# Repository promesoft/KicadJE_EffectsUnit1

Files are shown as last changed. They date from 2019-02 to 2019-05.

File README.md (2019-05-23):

# KicadJE_EffectsUnit1
JE-EU1 - PT2399 based reverb - distortion units
Eurorack form factor

# MK1 Design
## Status - operational
# Status - Secondary tests
## Initial 
| Stage  | Detail | Status |
| --- | --- | --- |
| create material  | sch/pcb | produced Rev A  |
| | gerber | Produced |
| production  | ordered  | YES |
|  | produced | YES |
|  | delivered | YES |
## Preliminary validation
| Test  | Detail | Status |
| --- | --- | --- |
| Initial Inspection |  | OK |
| Initial Technical Test | PT2399 | OK - See Errata |
| Initial Technical Test | Counter  | OK |
| Initial Technical Test | Bitcrunch |  |
| Initial Product Test | PT2399 | OK |
| Initial Product Test | Counter | OK |
| Initial Product Test | Bitcrunch  | OK - LFO w Distortion |
| Initial Power Consumption | PT2399 | 40-60mA ! +12v depending on VCO circuit |
| Initial Power Consumption | Counter | 20mA +12v  |
| Initial Power Consumption | Bitcrunch | +12v +5v -12v |
| Initial Power Consumption | LFO | +12v +5v -12v |

## Secondary validation
| Test  | Detail | Status |
| --- | --- |--- |
| Product Test | PT2399 | ok after mod |
| Product Test | Counter | OK |
| Product Test | LFO Distortion | OK - dist too much |
| Product Test | Bitcrush Distortion |  |
| Quality | LFO | good - distortion is questionable effect |
| Quality | Bitcrush |  |
| Quality | Counter | Good - needs input prot |
| Quality | PT2399 | ongoing |
| Long Term Product Test | PT2399 | Modded version installed in rack |
| Long Term Product Test | Counter | installed in rack |
| Long Term Product Test | Bitcrush |  |
| Long Term Product Test | LFO | installed in rack |

## Software 
| Test  | Detail | Status |
| --- | --- |--- |
| Initial SW | copy from MK1 and adjusted | OK! |
| Bitcrush | UI | |
| Bitcrush | Crush function | |
| LFO Control | UI | Individual speed and waveform impl |
| LFO Control | Function | Individual LFO implemented |
| LFO Control | Input | 3x Trigger done |

## Errata
### ERRATA - PT2399
 * 78L05 inv pinout
 * MMBT2222 wrong pinout - workaround flip and turn
 * Delay time pot reversed
 * PT2399 occational latchup with modification
 * SW101 and S105W are wired wrong to enable Dist on/off
### ERRATA - Counter
### ERRATA - Bitcrunch
 * SW 101 and SW105 should change footprint (too small for MT202)
 * D110 and D111 is 0805 and cannot be fitted with SOD123
## Issues and Notes
### Issues and Notes - PT2399
 * Replace 20k across Q203 w Yellow LED
 * Replace 120k R214 with 47k
 * Move C222 across RV202 - move D2015 across R214 and remove Q202+R213
 * Consider Vactrol of RV202 and RV201
 * Consider +5V supply...
### Issues and Notes - Counter
 * Replace 100uF C310 with 10-22uF (consider a switch for next rev)
 * Reset/Clk in Trigger not 5V tolerant
 * Add I/O protection

### Issues and Notes - Bit Crunch
LFO only values:
 * 11k = 10k
 * 22k = 10k
 * 33k = 10k
 * 44k = 10k
 * 11n = 100n
 * 22n = 100n
 * 33n = 100n
 * 44n = 100n
 * D118 - D117 remove
 * Optional D111 - D110
Dist/Bitcrush values has been added to the sch
 * Move LED D114 closer to Out9

### Workarounds

## Base Construction 
The idea is to have 3 different units.
Practically it may be required to fit the bitcrusher and the distortion in one unit.
### Distortion base board with Arduino Bitcrusher
 - 16pin Europower connector
 
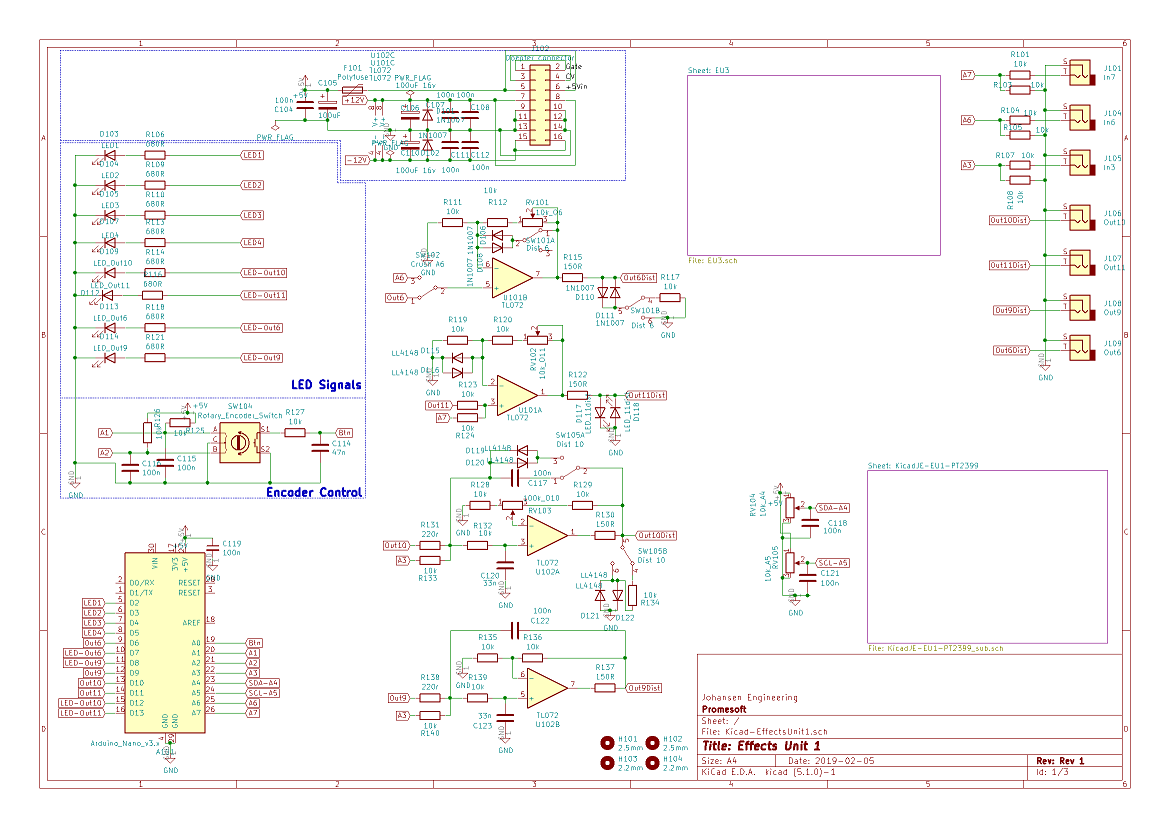
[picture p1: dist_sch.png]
 

### PT2399 base board 
 - 10pin Europower connector
 - BC547 or BC337 NPN and Zener 7v5 regulator followed by 78L05 regulator
 - PT2399 echo circuit with anti lockup circuit for pin 6
 - 
### Binary counter and clock
 - 10pin Europower connector
 - Build around a CD4017 counter chip (SOP-14)
 
 
 


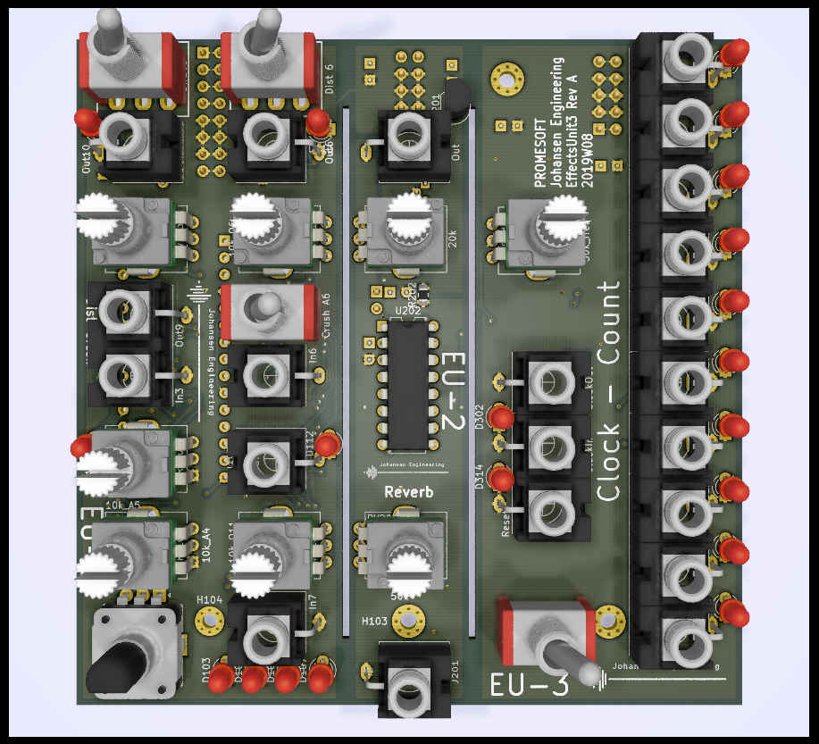
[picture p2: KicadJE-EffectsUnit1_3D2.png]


## Vital Components
 - Arduino Nano
 - PT2399
 - CD4017
 - NE555
 - Mini Jacks (PJ-321) 
 - ALPS RV09 potentiometer
 - TL072 or similar dual op amp
 - Diode clipping (silicium signal diodes, LED, power, shottkey, germanium
 
### Mechanical


The construction is inspired from
-----------------------------------------------------
 - https://www.electronics-tutorials.ws/waveforms/555_oscillator.html (Counter clock)
 - https://www.electrosmash.com/pt2399-analysis (PT2399 Reverb)
 - http://sim.okawa-denshi.jp/en/OPttool.php (Filter calc for MFB filter)
 - http://sim.okawa-denshi.jp/en/OPseikiLowkeisan.htm (Filter calc for Sallen Key filter (Out9 and Out10))

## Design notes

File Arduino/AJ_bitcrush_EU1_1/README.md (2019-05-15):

Left lower input is sampled as fast as possible

Output to all digital outputs with an AND function on the lower 16 bits with the "state" information equivalent to the LED readout

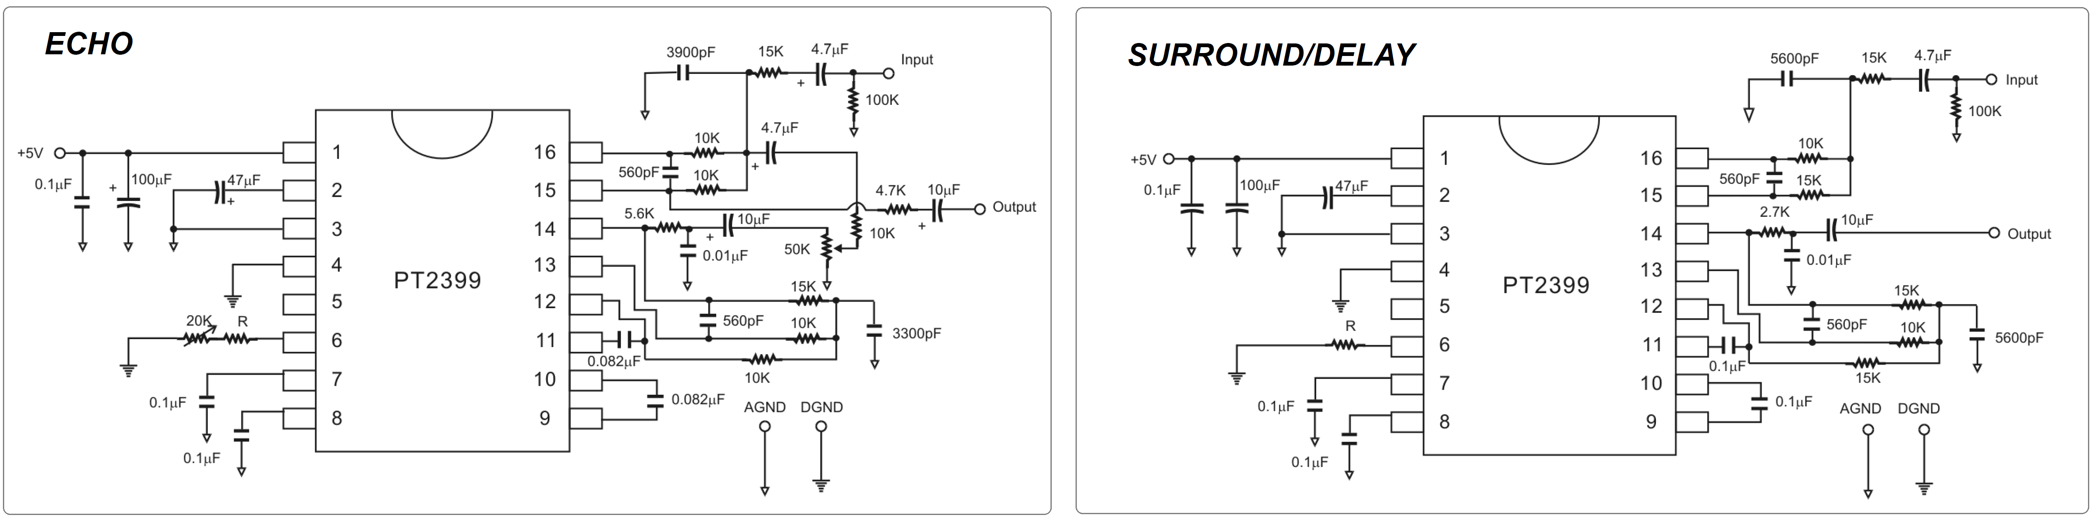
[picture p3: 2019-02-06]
PT2399_echo_delay.png

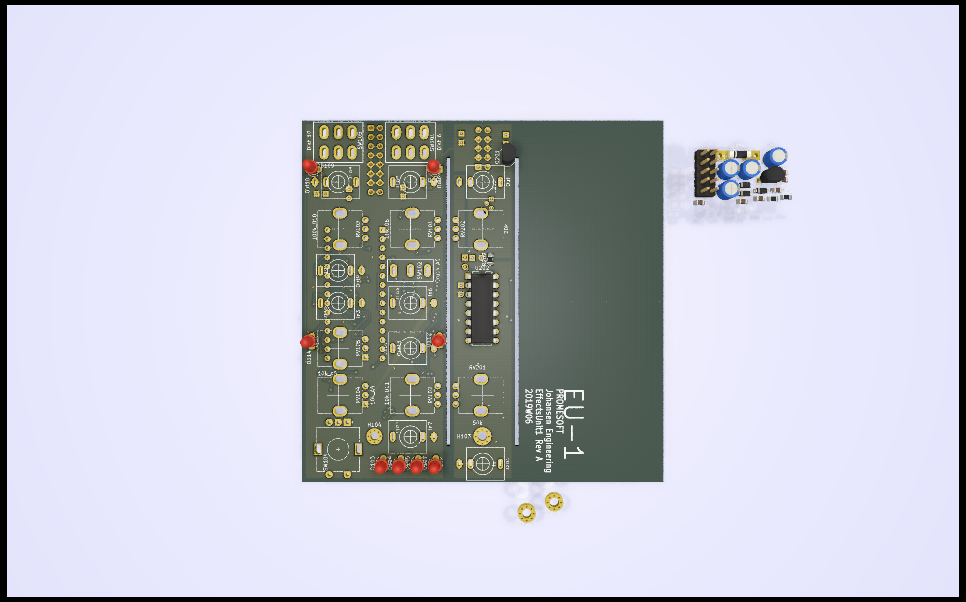
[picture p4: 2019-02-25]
KicadJE-EffectsUnit1_3D1.png

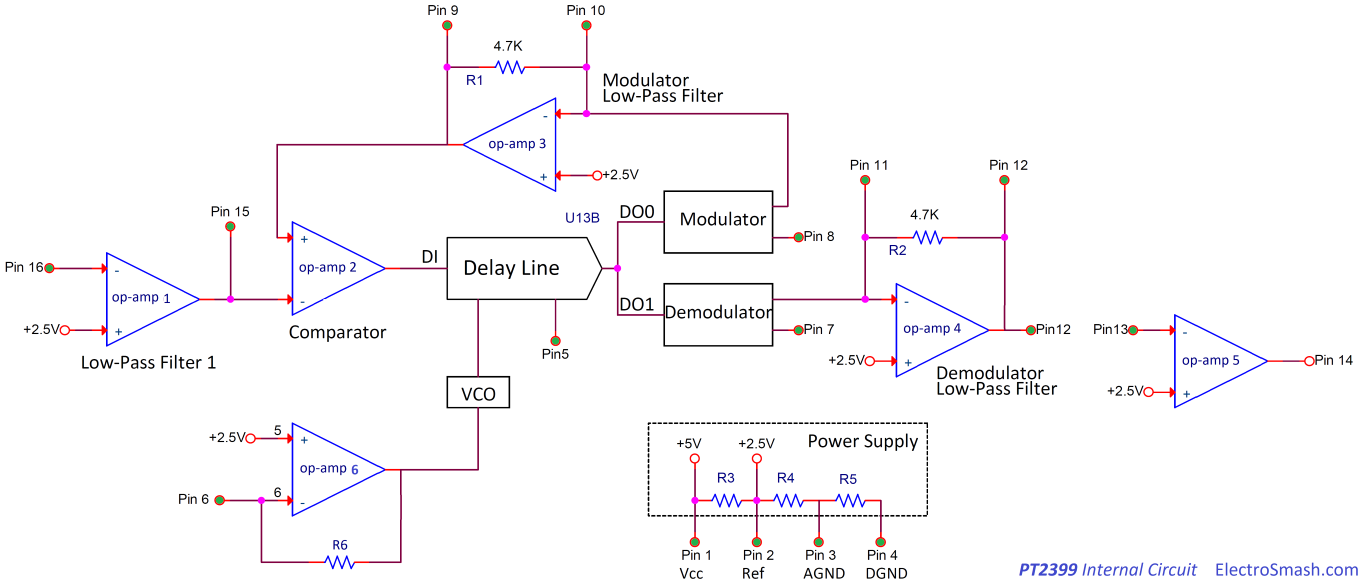
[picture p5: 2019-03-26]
PT2399_Internal_Circuit_small.png

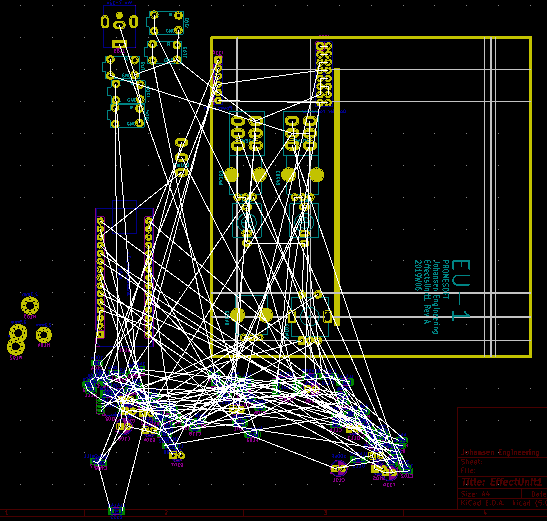
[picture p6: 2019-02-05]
KicadJE-EffectsUnit1.lib.png

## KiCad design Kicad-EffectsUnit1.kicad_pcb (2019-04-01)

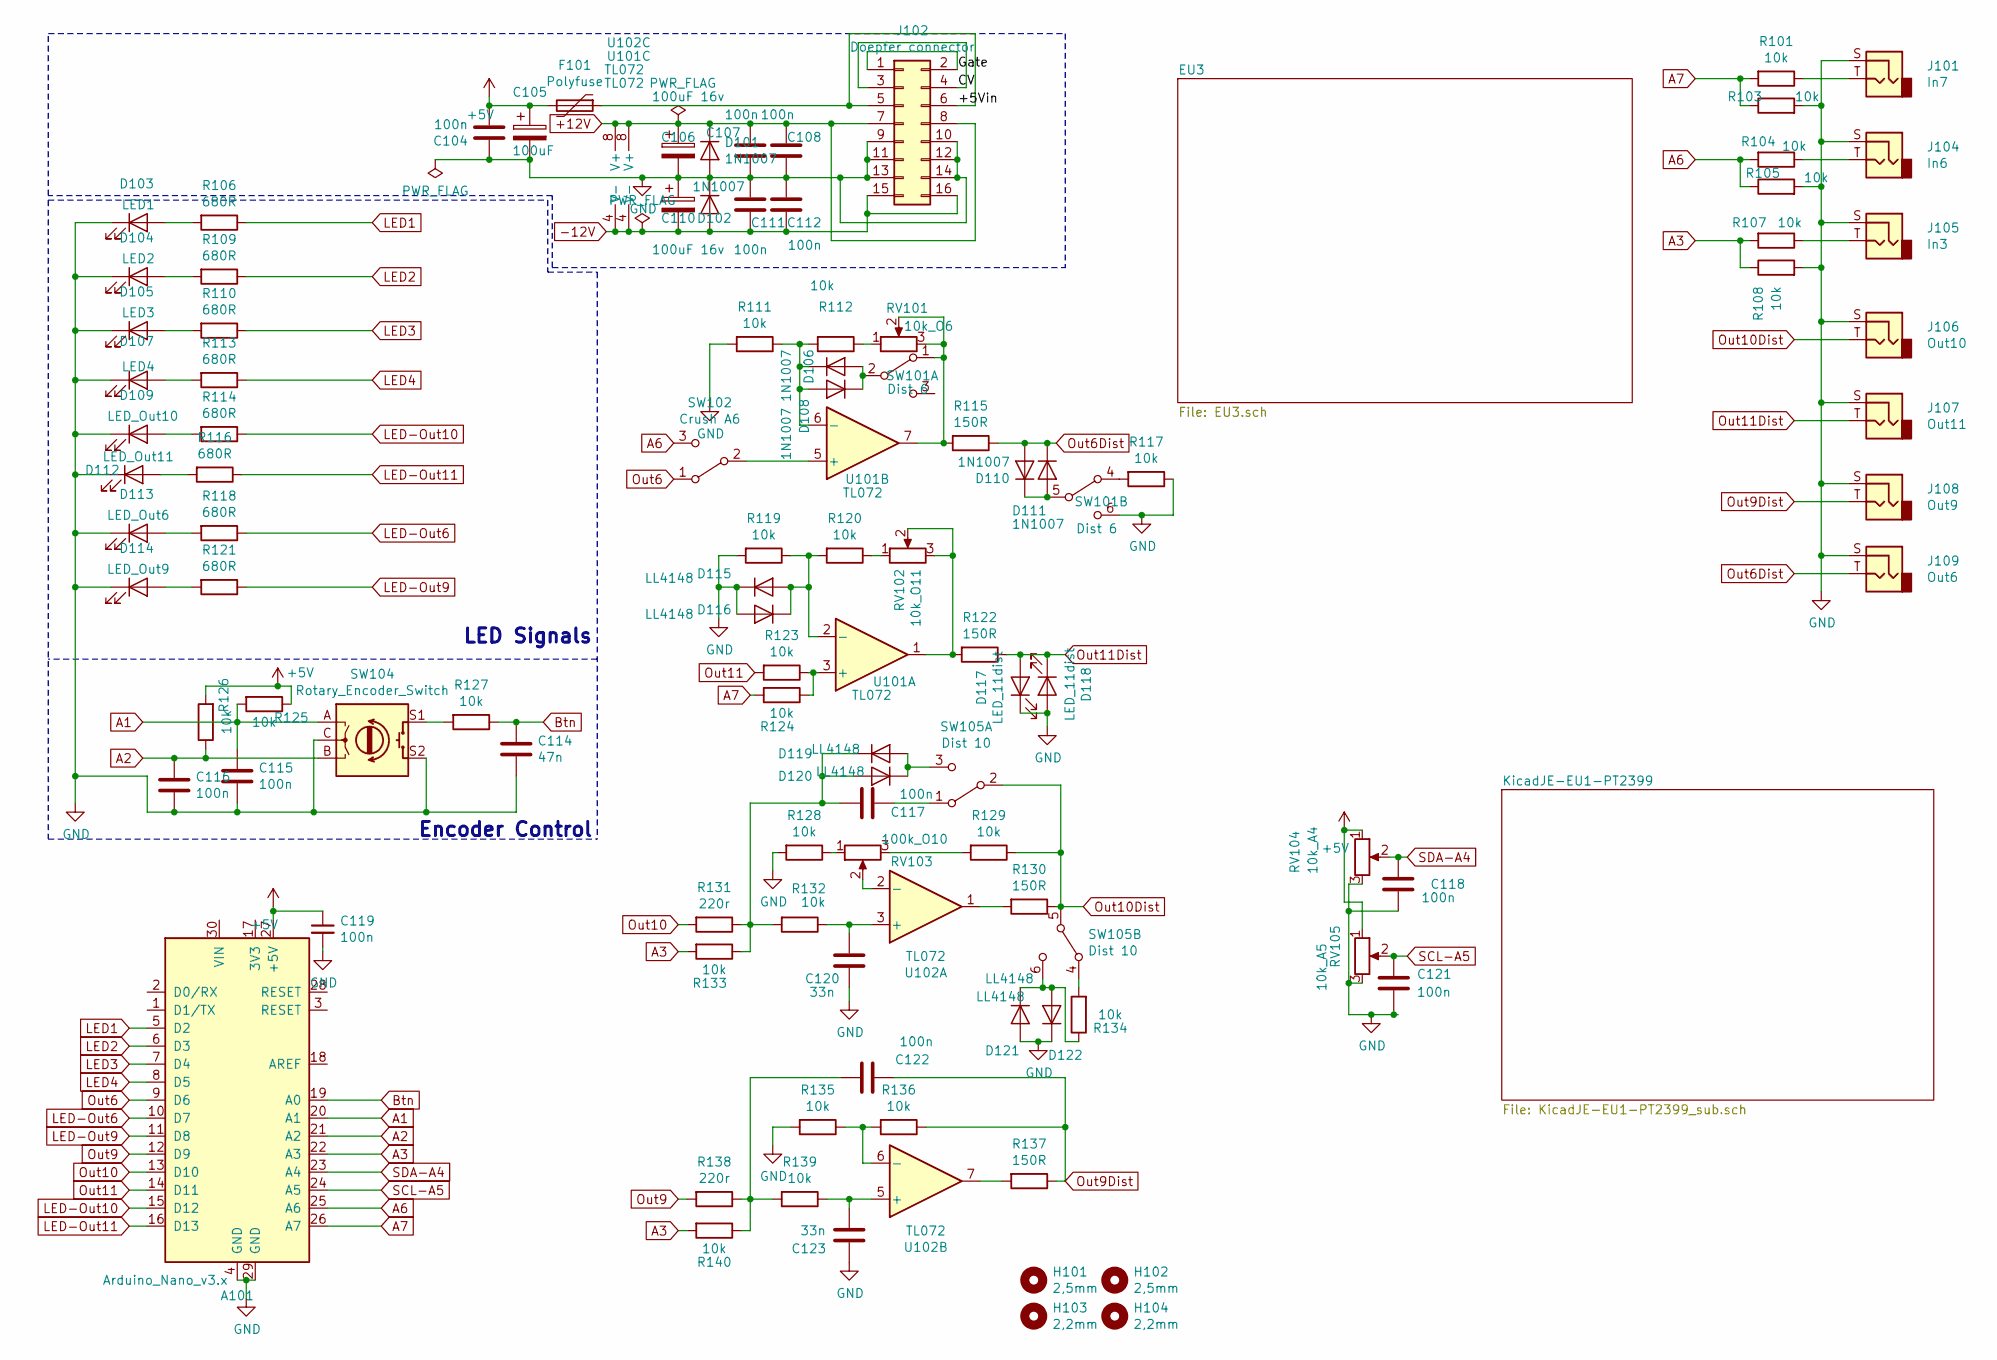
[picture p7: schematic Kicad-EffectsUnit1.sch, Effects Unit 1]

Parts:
A101: Arduino_Nano_v3.x; Arduino_Nano
C104, C107, C108, C111, C112, C115, C116, C117, C118, C119, C121, C122: 100n; C_0805_2012Metric_Pad1.15x1.40mm_HandSolder
C105: 100uF; CP_Radial_D5.0mm_P2.50mm
C106, C110: 100uF 16v; CP_Radial_D5.0mm_P2.50mm
C114: 47n; C_0805_2012Metric_Pad1.15x1.40mm_HandSolder
C120, C123: 33n; C_0805_2012Metric_Pad1.15x1.40mm_HandSolder
D101, D102, D106, D108: 1N1007; D_SOD-123
D103: LED1; LED_D3.0mm
D104: LED2; LED_D3.0mm
D105: LED3; LED_D3.0mm
D107: LED4; LED_D3.0mm
D109: LED_Out10; LED_D3.0mm
D110, D111: 1N1007; D_0805_2012Metric_Pad1.15x1.40mm_HandSolder
D112: LED_Out11; LED_D3.0mm
D113: LED_Out6; LED_D3.0mm
D114: LED_Out9; LED_D3.0mm
D115, D116, D119, D120, D121, D122: LL4148; D_MiniMELF
D117: LED_11dist; LED_0805_2012Metric_Pad1.15x1.40mm_HandSolder
D118: LED_11dist; D_0805_2012Metric_Pad1.15x1.40mm_HandSolder
F101: Polyfuse; Fuse_1206_3216Metric_Pad1.42x1.75mm_HandSolder
H101, H102: 2,5mm; MountingHole_2.5mm_Pad_Via
H103: 2,2mm; MountingHole_2.5mm_Pad_Via
H104: 2,2mm; MountingHole_2.2mm_M2_Pad_Via
J101: In7; PJ301SM
J102: Doepfer connector; PinSocket_2x08_P2.54mm_Vertical
J104: In6; PJ301SM
J105: In3; PJ301SM
J106: Out10; PJ301SM
J107: Out11; PJ301SM
J108: Out9; PJ301SM
J109: Out6; PJ301SM
R101, R103, R104, R105, R107, R108, R111, R112, R117, R119, R120, R123, R124, R125, R126, R127, R128, R129, R132, R133, R134, R135, R136, R139, R140: 10k; R_0805_2012Metric_Pad1.15x1.40mm_HandSolder
R106, R109, R110, R113, R114, R116, R118, R121: 680R; R_0805_2012Metric_Pad1.15x1.40mm_HandSolder
R115, R122, R130, R137: 150R; R_0805_2012Metric_Pad1.15x1.40mm_HandSolder
R131, R138: 220r; R_0805_2012Metric_Pad1.15x1.40mm_HandSolder
RV101: 10k_O6; Potentiometer_China_RK09_Single_Vertical_AJ
RV102: 10k_O11; Potentiometer_China_RK09_Single_Vertical_AJ
RV103: 100k_O10; Potentiometer_China_RK09_Single_Vertical_AJ
RV104: 10k_A4; Potentiometer_China_RK09_Single_Vertical_AJ
RV105: 10k_A5; Potentiometer_China_RK09_Single_Vertical_AJ
SW101: Dist 6; SPDTx2
SW102: Crush A6; SP1MS1
SW104: Rotary_Encoder_Switch; RotaryEncoder_Alps_EC11E-Switch_Vertical_H20mm
SW105: Dist 10; SPDTx2
U101, U102: TL072; AJ_SO-8_5.3x6.2mm_P1.27mm

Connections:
+5V: A101.27 (+5V), C104.2, C105.1, C119.1, F101.2, R125.1, R126.2, RV104.1, RV105.1
+12V: C106.1, C107.2, C108.2, D101.1 (K), J102.7, J102.8, U101.8 (V+), U102.8 (V+)
-12V: C110.2, C111.1, C112.1, D102.2 (A), J102.15, J102.16, U101.4 (V-), U102.4 (V-)
/+5Vin: F101.1, J102.5, J102.6
/CV: J102.3, J102.4
/Gate: J102.1, J102.2
A1: A101.20 (A1), C115.1, R125.2, SW104.A
A2: A101.21 (A2), C116.1, R126.1, SW104.B
A3: A101.22 (A3), R107.2, R108.1, R133.2, R140.2
A6: A101.25 (A6), R104.2, R105.1, SW102.3 (C)
A7: A101.26 (A7), R101.2, R103.1, R124.2
Btn: A101.19 (A0), C114.1, R127.1
GND: A101.4 (GND), A101.29 (GND), C104.1, C105.2, C106.2, C107.1, C108.1, C110.1, C111.2, C112.2, C114.2, C115.2, C116.2, C118.2, C119.2, C120.2, C121.2, C123.2, D101.2 (A), D102.1 (K), D103.1 (K), D104.1 (K), D105.1 (K), D107.1 (K), D109.1 (K), D112.1 (K), D113.1 (K), D114.1 (K), D115.1 (K), D116.2 (A), D117.1 (K), D118.2 (A), D121.2 (A), D122.1 (K), J101.S, J102.9, J102.10, J102.11, J102.12, J102.13, J102.14, J104.S, J105.S, J106.S, J107.S, J108.S, J109.S, R103.2, R105.2, R108.2, R111.2, R117.1, R119.2, R128.2, R135.2, RV104.3, RV105.3, SW101.6 (C), SW104.C, SW104.S2; also elsewhere on the board
LED1: A101.5 (D2), R106.1
LED2: A101.6 (D3), R109.1
LED3: A101.7 (D4), R110.1
LED4: A101.8 (D5), R113.1
LED-Out6: A101.10 (D7), R118.1
LED-Out9: A101.11 (D8), R121.1
LED-Out10: A101.15 (D12), R114.1
LED-Out11: A101.16 (D13), R116.1
unnamed: C117.1, SW105.1 (A)
unnamed: C117.2, D119.1 (K), D120.2 (A), R131.1, R132.2, R133.1
unnamed: C120.1, R132.1, U102.3 (+)
unnamed: C122.2, R138.1, R139.2, R140.1
unnamed: C123.1, R139.1, U102.5 (+)
unnamed: D103.2 (A), R106.2
unnamed: D104.2 (A), R109.2
unnamed: D105.2 (A), R110.2
unnamed: D106.1 (K), D108.2 (A), R111.1, R112.2, U101.6 (-)
unnamed: D106.2 (A), D108.1 (K), SW101.2 (B)
unnamed: D107.2 (A), R113.2
unnamed: D109.2 (A), R114.2
unnamed: D110.1 (K), D111.2 (A), SW101.5 (B)
unnamed: D112.2 (A), R116.2
unnamed: D113.2 (A), R118.2
unnamed: D114.2 (A), R121.2
unnamed: D115.2 (A), D116.1 (K), R119.1, R120.2, U101.2 (-)
unnamed: D119.2 (A), D120.1 (K), SW105.3 (C)
unnamed: D121.1 (K), D122.2 (A), R134.1, SW105.6 (C)
unnamed: J101.T, R101.1
unnamed: J104.T, R104.1
unnamed: J105.T, R107.1
unnamed: R112.1, RV101.1
unnamed: R115.2, RV101.2, RV101.3, SW101.1 (A), U101.7
unnamed: R117.2, SW101.4 (A)
unnamed: R120.1, RV102.1
unnamed: R122.2, RV102.2, RV102.3, U101.1
unnamed: R123.1, R124.1, U101.3 (+)
unnamed: R127.2, SW104.S1
unnamed: R128.1, RV103.1
unnamed: R129.2, RV103.3
unnamed: R130.2, U102.1
unnamed: R134.2, SW105.4 (A)
unnamed: R135.1, R136.2, U102.6 (-)
unnamed: R137.2, U102.7
unnamed: RV103.2, U102.2 (-)
unnamed: SW102.2 (B), U101.5 (+)
Out6: A101.9 (D6), SW102.1 (A); also elsewhere on the board
Out6Dist: D110.2 (A), D111.1 (K), J109.T, R115.1
Out9: A101.12 (D9), R138.2; also elsewhere on the board
Out9Dist: C122.1, J108.T, R136.1, R137.1
Out10: A101.13 (D10), R131.2
Out10Dist: J106.T, R129.1, R130.1, SW105.2 (B), SW105.5 (B)
Out11: A101.14 (D11), R123.2
Out11Dist: D117.2 (A), D118.1 (K), J107.T, R122.1
SCL-A5: A101.24 (A5), C121.1, RV105.2
SDA-A4: A101.23 (A4), C118.1, RV104.2

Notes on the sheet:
LED Signals
Encoder Control

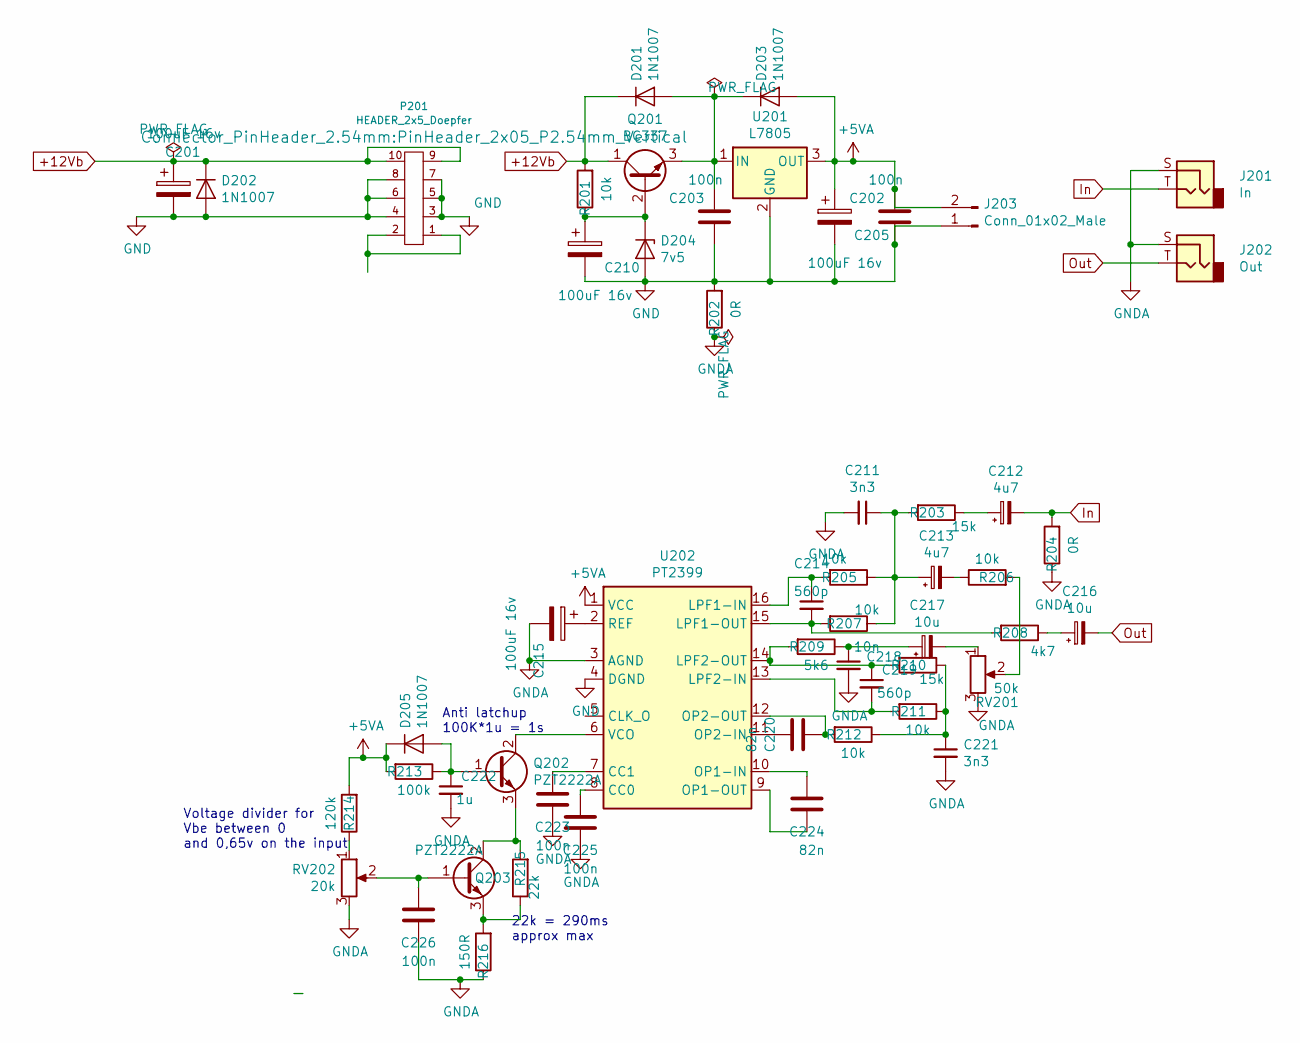
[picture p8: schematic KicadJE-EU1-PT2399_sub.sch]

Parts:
C201, C205, C210, C215: 100uF 16v; CP_Radial_D5.0mm_P2.50mm
C202, C203, C223, C225, C226: 100n; C_0805_2012Metric_Pad1.15x1.40mm_HandSolder
C211, C221: 3n3; C_0805_2012Metric_Pad1.15x1.40mm_HandSolder
C212, C213: 4u7; C_0805_2012Metric_Pad1.15x1.40mm_HandSolder
C214, C219: 560p; C_0805_2012Metric_Pad1.15x1.40mm_HandSolder
C216, C217: 10u; C_0805_2012Metric_Pad1.15x1.40mm_HandSolder
C218: 10n; C_0805_2012Metric_Pad1.15x1.40mm_HandSolder
C220, C224: 82n; C_0805_2012Metric_Pad1.15x1.40mm_HandSolder
C222: 1u; C_0805_2012Metric_Pad1.15x1.40mm_HandSolder
D201, D202, D203, D205: 1N1007; D_SOD-123
D204: 7v5; D_MiniMELF
J201: In; PJ301SM
J202: Out; PJ301SM
J203: Conn_01x02_Male; PinHeader_1x02_P2.54mm_Vertical
P201: HEADER_2x5_Doepfer; PinHeader_2x05_P2.54mm_Vertical
Q201: BC337; TO-92_Inline
Q202, Q203: PZT2222A; SOT-23
R201, R205, R206, R207, R211, R212: 10k; R_0805_2012Metric_Pad1.15x1.40mm_HandSolder
R202, R204: 0R; R_0805_2012Metric_Pad1.15x1.40mm_HandSolder
R203, R210: 15k; R_0805_2012Metric_Pad1.15x1.40mm_HandSolder
R208: 4k7; R_0805_2012Metric_Pad1.15x1.40mm_HandSolder
R209: 5k6; R_0805_2012Metric_Pad1.15x1.40mm_HandSolder
R213: 100k; R_0805_2012Metric_Pad1.15x1.40mm_HandSolder
R214: 120k; R_0805_2012Metric_Pad1.15x1.40mm_HandSolder
R215: 22k; R_0805_2012Metric_Pad1.15x1.40mm_HandSolder
R216: 150R; R_0805_2012Metric_Pad1.15x1.40mm_HandSolder
RV201: 50k; Potentiometer_China_RK09_Single_Vertical_AJ
RV202: 20k; Potentiometer_China_RK09_Single_Vertical_AJ
U201: L7805; TO-92
U202: PT2399; DIP-16_W7.62mm

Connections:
+5VA: C202.2, C205.1, D203.2 (A), D205.1 (K), J203.2, R213.2, R214.2, U201.3 (OUT), U202.1 (VCC)
+12Vb: C201.1, D201.1 (K), D202.1 (K), P201.9 (+12), P201.10 (+12), Q201.1 (C), R201.2
GND: C201.2, C202.1, C203.1, C205.2, C210.2, D202.2 (A), D204.2 (A), J203.1, P201.3 (GND), P201.4 (GND), P201.5 (GND), P201.6 (GND), P201.7 (GND), P201.8 (GND), R202.2, U201.2 (GND), U202.4 (DGND); also elsewhere on the board
GNDA: C211.2, C215.2, C218.2, C221.2, C222.2, C223.1, C225.1, C226.1, J201.S, J202.S, R202.1, R204.1, R216.1, RV201.3, RV202.3, U202.3 (AGND)
In: C212.2, J201.T, R204.2
unnamed: C203.2, D201.2 (A), D203.1 (K), Q201.3 (E), U201.1 (IN)
unnamed: C210.1, D204.1 (K), Q201.2 (B), R201.1
unnamed: C211.1, C213.1, R203.2, R205.1, R207.1
unnamed: C212.1, R203.1
unnamed: C213.2, R206.1
unnamed: C214.1, R205.2, U202.16 (LPF1-IN)
unnamed: C214.2, R207.2, R208.2, U202.15 (LPF1-OUT)
unnamed: C215.1, U202.2 (REF)
unnamed: C216.1, R208.1
unnamed: C217.1, C218.1, R209.1
unnamed: C217.2, RV201.1
unnamed: C219.1, R209.2, R210.2, U202.14 (LPF2-OUT)
unnamed: C219.2, R211.2, U202.13 (LPF2-IN)
unnamed: C220.1, U202.11 (OP2-IN)
unnamed: C220.2, R212.2, U202.12 (OP2-OUT)
unnamed: C221.1, R210.1, R211.1, R212.1
unnamed: C222.1, D205.2 (A), Q202.1 (B), R213.1
unnamed: C223.2, U202.7 (CC1)
unnamed: C224.1, U202.9 (OP1-OUT)
unnamed: C224.2, U202.10 (OP1-IN)
unnamed: C225.2, U202.8 (CC0)
unnamed: C226.2, Q203.1 (B), RV202.2
unnamed: P201.1 (-12), P201.2 (-12)
unnamed: Q202.2 (C), U202.6 (VCO)
unnamed: Q202.3 (E), Q203.2 (C), R215.2
unnamed: Q203.3 (E), R215.1, R216.2
unnamed: R206.2, RV201.2
unnamed: R214.1, RV202.1
Out: C216.2, J202.T

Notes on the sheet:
Voltage divider for Vbe between 0 and 0,65v on the input
Anti latchup 100K*1u = 1s
22k = 290ms approx max

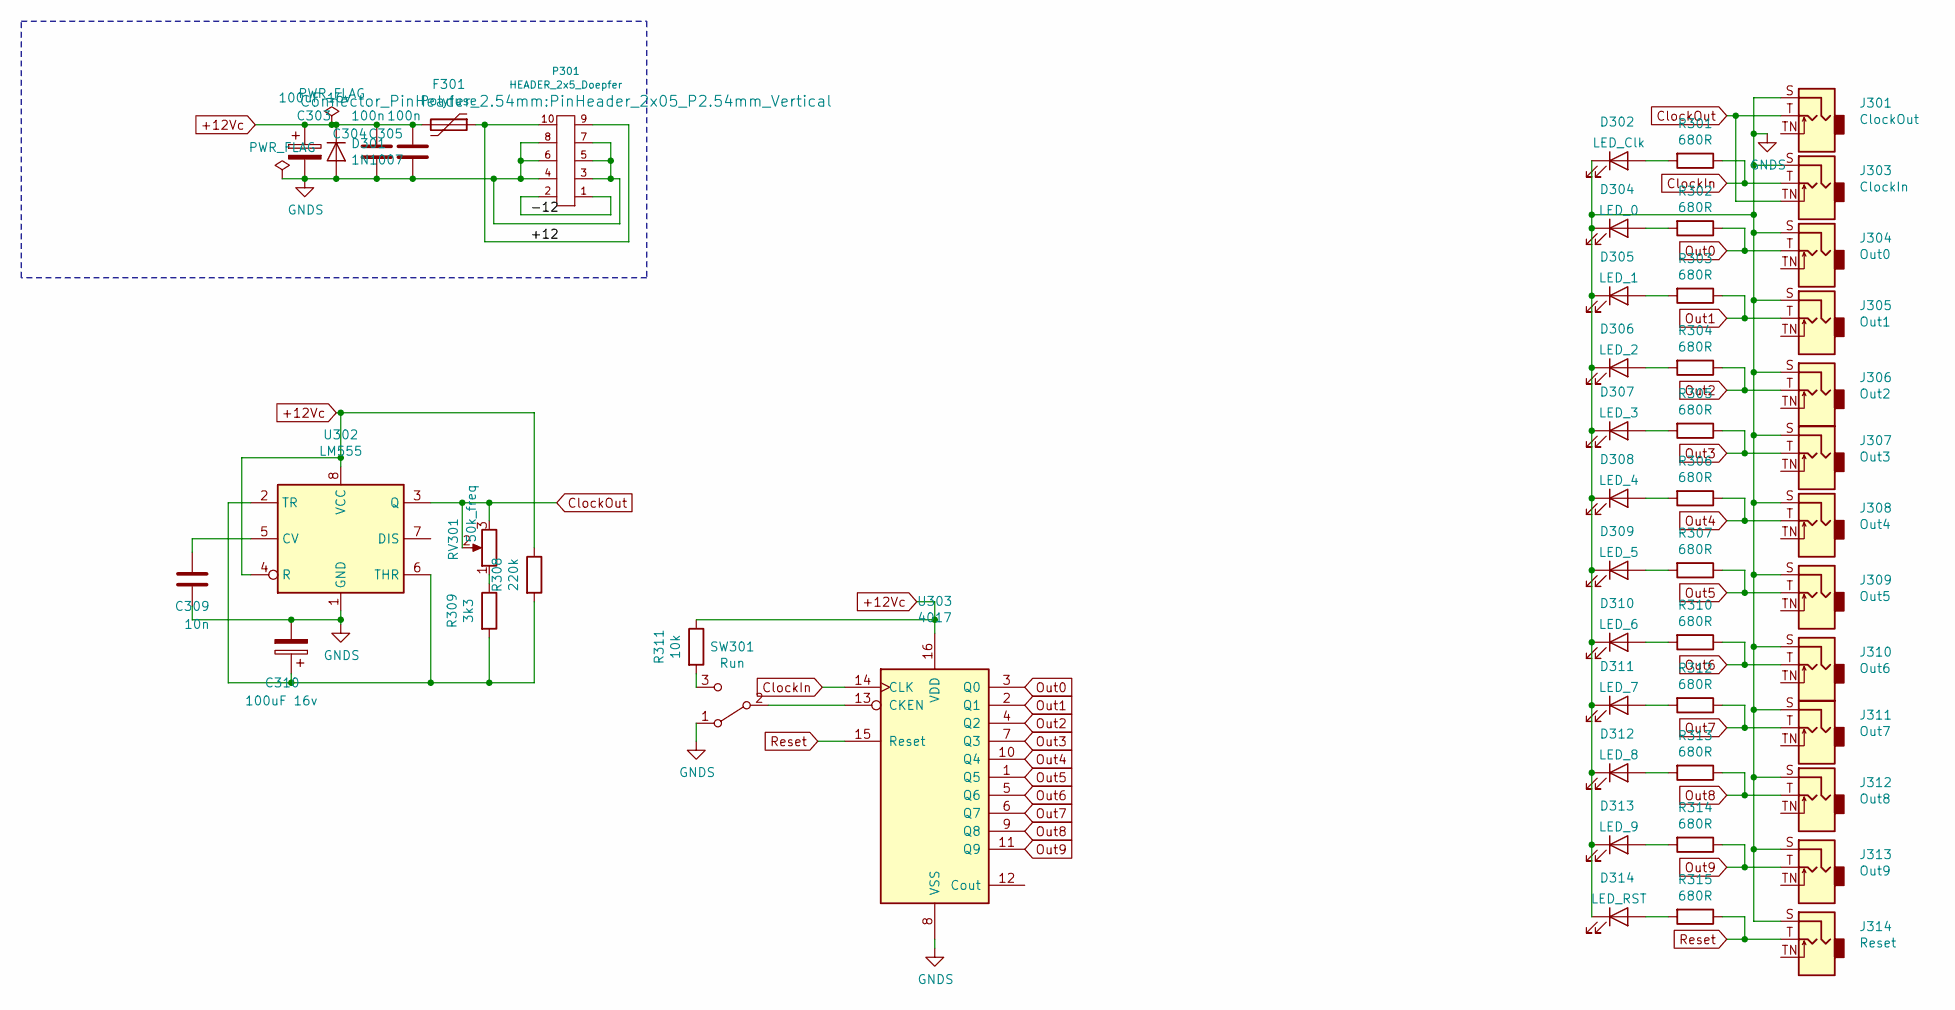
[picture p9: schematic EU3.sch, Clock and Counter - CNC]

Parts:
C303, C310: 100uF 16v; CP_Radial_D5.0mm_P2.50mm
C304, C305: 100n; C_0805_2012Metric_Pad1.15x1.40mm_HandSolder
C309: 10n; C_0805_2012Metric_Pad1.15x1.40mm_HandSolder
D301: 1N1007; D_SOD-123
D302: LED_Clk; LED_D3.0mm
D304: LED_0; LED_D3.0mm
D305: LED_1; LED_D3.0mm
D306: LED_2; LED_D3.0mm
D307: LED_3; LED_D3.0mm
D308: LED_4; LED_D3.0mm
D309: LED_5; LED_D3.0mm
D310: LED_6; LED_D3.0mm
D311: LED_7; LED_D3.0mm
D312: LED_8; LED_D3.0mm
D313: LED_9; LED_D3.0mm
D314: LED_RST; LED_D3.0mm
F301: Polyfuse; Fuse_1206_3216Metric_Pad1.42x1.75mm_HandSolder
J301: ClockOut; PJ301SM
J303: ClockIn; PJ301SM
J304: Out0; PJ301SM
J305: Out1; PJ301SM
J306: Out2; PJ301SM
J307: Out3; PJ301SM
J308: Out4; PJ301SM
J309: Out5; PJ301SM
J310: Out6; PJ301SM
J311: Out7; PJ301SM
J312: Out8; PJ301SM
J313: Out9; PJ301SM
J314: Reset; PJ301SM
P301: HEADER_2x5_Doepfer; PinHeader_2x05_P2.54mm_Vertical
R301, R302, R303, R304, R305, R306, R307, R310, R312, R313, R314, R315: 680R; R_0805_2012Metric_Pad1.15x1.40mm_HandSolder
R308: 220k; R_0805_2012Metric_Pad1.15x1.40mm_HandSolder
R309: 3k3; R_0805_2012Metric_Pad1.15x1.40mm_HandSolder
R311: 10k; R_0805_2012Metric_Pad1.15x1.40mm_HandSolder
RV301: 50k_freq; Potentiometer_China_RK09_Single_Vertical_AJ
SW301: Run; SP1MS1
U302: LM555; AJ_SO-8_5.3x6.2mm_P1.27mm
U303: 4017; SOIC-16_4.55x10.3mm_P1.27mm

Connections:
+12Vc: C303.1, C304.2, C305.2, D301.1 (K), F301.2, R308.1, R311.1, U302.4 (R), U302.8 (VCC), U303.16 (VDD)
ClockIn: J303.T, R301.1, U303.14 (CLK)
ClockOut: J301.T, J303.TN, RV301.2, RV301.3, U302.3 (Q)
GNDS: C303.2, C304.1, C305.1, C309.1, C310.2, D301.2 (A), D302.1 (K), D304.1 (K), D305.1 (K), D306.1 (K), D307.1 (K), D308.1 (K), D309.1 (K), D310.1 (K), D311.1 (K), D312.1 (K), D313.1 (K), D314.1 (K), J301.S, J303.S, J304.S, J305.S, J306.S, J307.S, J308.S, J309.S, J310.S, J311.S, J312.S, J313.S, J314.S, P301.3 (GND), P301.4 (GND), P301.5 (GND), P301.6 (GND), P301.7 (GND), P301.8 (GND), SW301.1 (A), U302.1 (GND), U303.8 (VSS)
unnamed: C309.2, U302.5 (CV)
unnamed: C310.1, R308.2, R309.2, U302.2 (TR), U302.6 (THR)
unnamed: D302.2 (A), R301.2
unnamed: D304.2 (A), R302.2
unnamed: D305.2 (A), R303.2
unnamed: D306.2 (A), R304.2
unnamed: D307.2 (A), R305.2
unnamed: D308.2 (A), R306.2
unnamed: D309.2 (A), R307.2
unnamed: D310.2 (A), R310.2
unnamed: D311.2 (A), R312.2
unnamed: D312.2 (A), R313.2
unnamed: D313.2 (A), R314.2
unnamed: D314.2 (A), R315.2
unnamed: F301.1, P301.9 (+12), P301.10 (+12)
unnamed: P301.1 (-12), P301.2 (-12)
unnamed: R309.1, RV301.1
unnamed: R311.2, SW301.3 (C)
unnamed: SW301.2 (B), U303.13 (CKEN)
Out0: J304.T, R302.1, U303.3 (Q0)
Out1: J305.T, R303.1, U303.2 (Q1)
Out2: J306.T, R304.1, U303.4 (Q2)
Out3: J307.T, R305.1, U303.7 (Q3)
Out4: J308.T, R306.1, U303.10 (Q4)
Out5: J309.T, R307.1, U303.1 (Q5)
Out6: J310.T, R310.1, U303.5 (Q6); also elsewhere on the board
Out7: J311.T, R312.1, U303.6 (Q7)
Out8: J312.T, R313.1, U303.9 (Q8)
Out9: J313.T, R314.1, U303.11 (Q9); also elsewhere on the board
Reset: J314.T, R315.1, U303.15 (Reset)

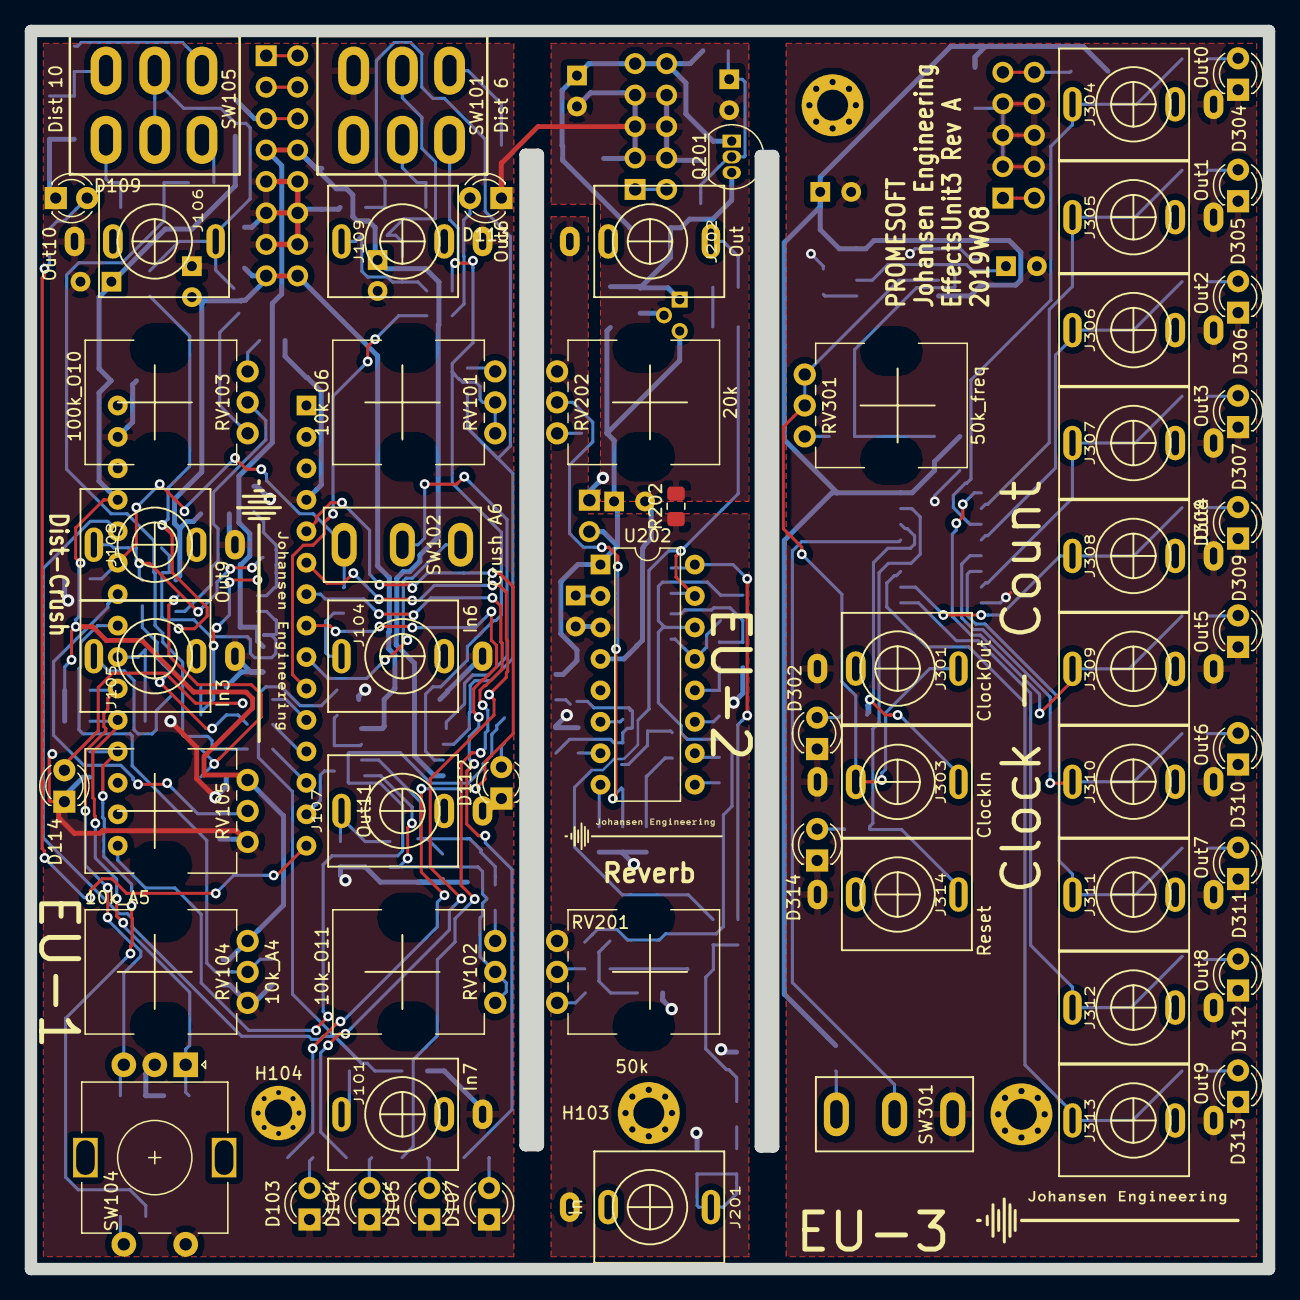
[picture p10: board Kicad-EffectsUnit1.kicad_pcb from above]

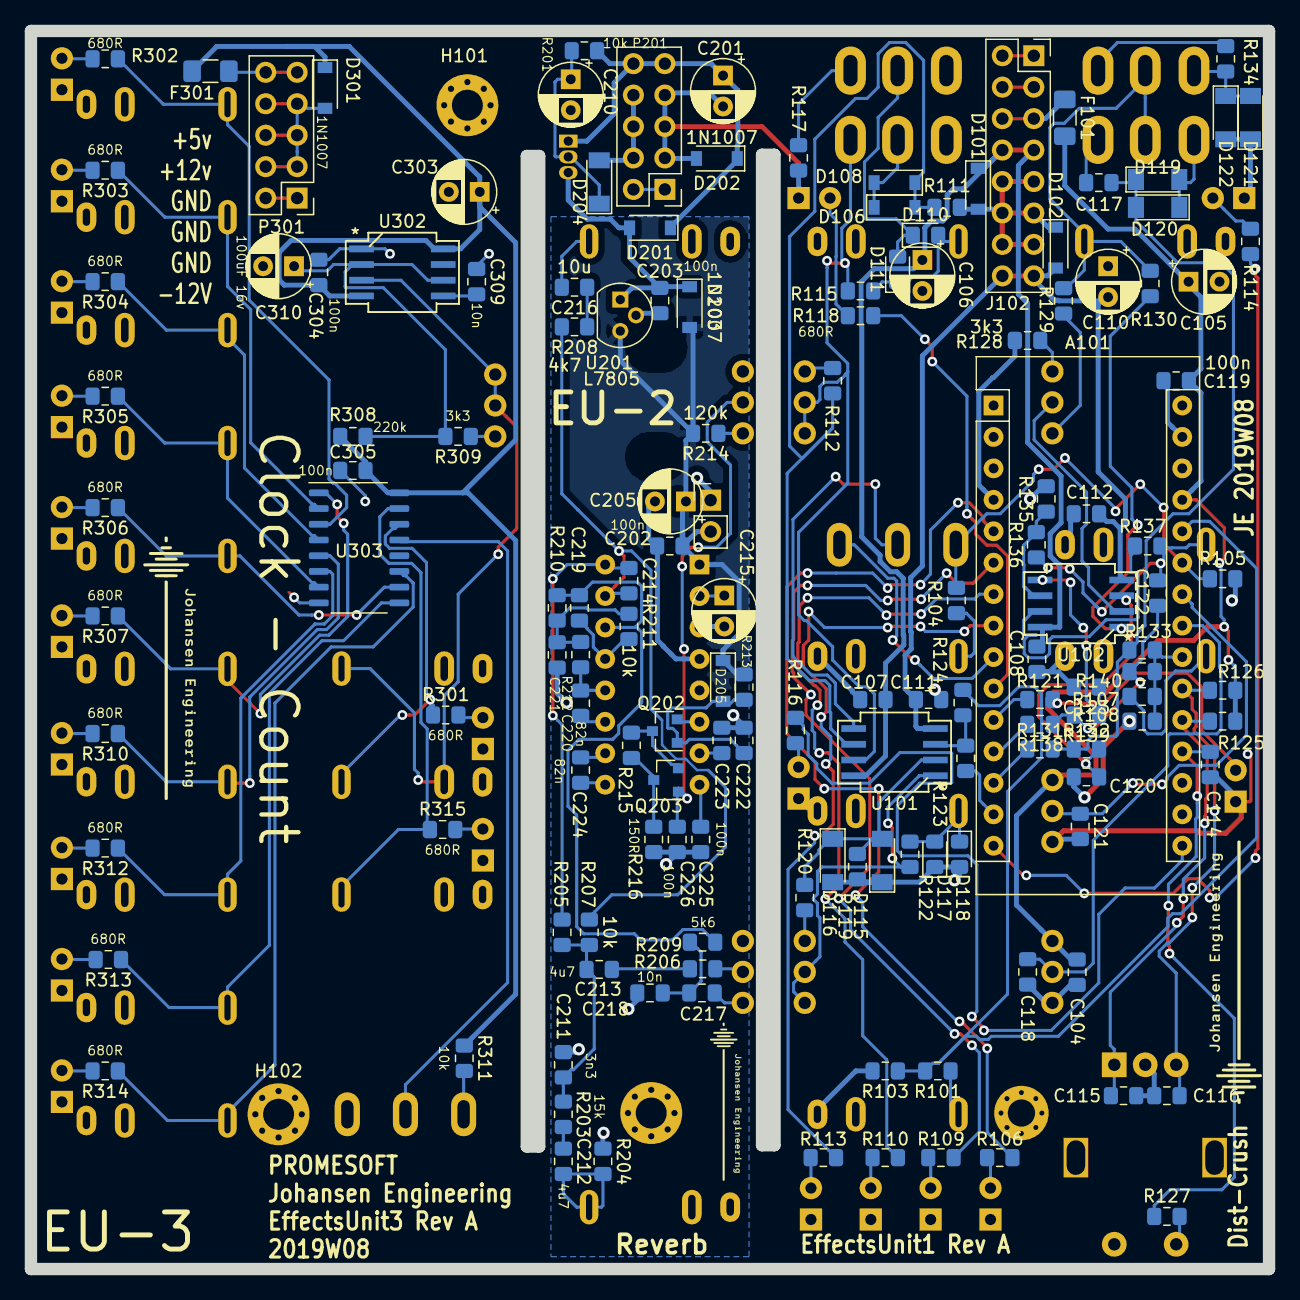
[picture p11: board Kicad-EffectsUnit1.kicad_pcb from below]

Board: 2 copper layers, 100.0 x 100.0 mm, 209 parts (149 on the bottom side), 133 nets.

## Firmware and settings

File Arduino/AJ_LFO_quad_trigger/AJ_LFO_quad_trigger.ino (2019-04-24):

/* 
 * Wavetable LFO inspiration: 
 * https://www.muffwiggler.com/forum/viewtopic.php?t=169706&sid=4b0d7d4af599d0df3e7b6fc29ece21b8 
 *  
 *  TODO: 
 *  Input triggers new counter reset
 *  Save Pot state
 */ 

#include "wavetable.h";
#include "globals.h";


/* =====================================================
==============INIT DATA STRUCTURES======================
======================================================*/  
void setupDataStruct(){
   LFO_CH[0][3] = LFO0_pin;              // [LFO Ch0]  [PWMpin]
   LFO_CH[0][4] = LED_Out6;              // [LFO Ch0]  [LEDpin] 
   LFO_CH[1][3] = LFO1_pin;              // [LFO Ch1]  [PWMpin]
   LFO_CH[1][4] = LED_Out9;              // [LFO Ch1]  [LEDpin] 
   LFO_CH[2][3] = LFO2_pin;              // [LFO Ch2]  [PWMpin]
   LFO_CH[2][4] = LED_Out10;             // [LFO Ch2]  [LEDpin] 
   LFO_CH[3][3] = LFO3_pin;              // [LFO Ch3]  [PWMpin]
   LFO_CH[3][4] = LED_Out11;             // [LFO Ch3]  [LEDpin] 
   Serial.println("");
   for (int i=0; i <= 3; i++){
     for (int j=0; j <= 3; j++){
      LEDData[i][j]=false;
     }
     LFO_CH[i][0] = EEPROM.read(i);              // [LFO Ch0-3]  [State,Counter,LastUpdate,PWMpin,LEDpin,StepA4,DelayA5]
     LFO_CH[i][5] = EEPROM.read(i+StepA4EEPROM);              // [LFO Ch0-3]  [State,Counter,LastUpdate,PWMpin,LEDpin,StepA4,DelayA5]
     LFO_CH[i][6] = EEPROM.read(i+StepA5EEPROM);              // [LFO Ch0-3]  [State,Counter,LastUpdate,PWMpin,LEDpin,StepA4,DelayA5]
     if (LFO_CH[i][0] > 15) LFO_CH[i][0] = 0;
     updateLEDValue(LFO_CH[i][0], i);
     encoder[i] = LFO_CH[i][0] << 2;
     LFO_CH[i][1] = 0;              // [LFO Ch0-3]  [Counter]
     LFO_CH[i][2] = 0;              // [LFO Ch0-3]  [LastUpdate]
     //LFO_CH[i][5] = 1;              // [LFO Ch0-3]  [StepA4]
     //LFO_CH[i][6] = 1;              // [LFO Ch0-3]  [DelayA5]   
     lastwaveupdate[i] = 0;  
   Serial.print("LFO");
   Serial.print(i);
   Serial.print(",");
   Serial.print(LFO_CH[i][0]);
   Serial.print(",");
   Serial.print(LFO_CH[i][1]);
   Serial.print(",");
   Serial.print(LFO_CH[i][2]);
   Serial.print(",");
   Serial.print(LFO_CH[i][3]);
   Serial.print(",");
   Serial.print(LFO_CH[i][4]);
   Serial.print(",");
   Serial.print(LFO_CH[i][5]);
   Serial.print(",");
   Serial.println(LFO_CH[i][6]);
   }
}
/* =====================================================
==============SETUP=====================================
======================================================*/  
void setup() {  
  Serial.begin(38400);
  Serial.println();
  Serial.println("");
  Serial.println(F(__FILE__));
  Serial.print(F("Build date: "));
  Serial.println(F(__DATE__));
  delay(50);  
  setupDataStruct();
  
/* ===========Encoder Setup=============================*/
  pinMode(SWpin, INPUT);
  pinMode(Apin, INPUT);
  pinMode(Bpin, INPUT);
  // Enable internal pull-up resistors
  digitalWrite(SWpin, HIGH);
  digitalWrite(Apin, HIGH);
  digitalWrite(Bpin, HIGH);

/* ===========LED Setup=================================*/
  pinMode(LED1, OUTPUT);
  pinMode(LED2, OUTPUT);
  pinMode(LED3, OUTPUT);
  pinMode(LED4, OUTPUT);
  pinMode(LED_Out6, OUTPUT);
  pinMode(LED_Out9, OUTPUT);
  pinMode(LED_Out10, OUTPUT);
  pinMode(LED_Out11, OUTPUT);
    
  digitalWrite(LED1, HIGH);
  digitalWrite(LED2, HIGH);
  digitalWrite(LED3, HIGH);
  digitalWrite(LED4, HIGH);
  digitalWrite(LED_Out6, HIGH);
  digitalWrite(LED_Out9, HIGH);
  digitalWrite(LED_Out10, HIGH);
  digitalWrite(LED_Out11, HIGH);
  delay(150);

  updateLED();

/* =========Setup LFO Output pins=======================*/
  pinMode(LFO0_pin, OUTPUT);                           // Sets Pin 6 PWM1
  pinMode(LFO1_pin, OUTPUT);                           // Sets Pin 9 PWM2
  pinMode(LFO2_pin, OUTPUT);                           // Sets Pin 10 PWM3
  pinMode(LFO3_pin, OUTPUT);                           // Sets Pin 11 PWM3

/* =========Setup Trigger Input pins====================*/
  pinMode(RightCenterIn, INPUT);                       // Sets Pin 
  pinMode(RightBottomIn, INPUT);                       // Sets Pin 
  pinMode(LeftIn, INPUT);                              // Sets Pin 
/* =========Enable interrupt on A0,1,2==================*/
  // 1. PCIE1: Pin Change Interrupt Enable 1
  PCICR =  0b00000010; 
  // Enable Pin Change Interrupt for A0, A1, A2
  PCMSK1 = 0b00000111; 

  delay(100); 
/* =====================================================*/

} 

/* =====================================================
==============MAIN LOOP=================================
======================================================*/  
void loop() { 
  checkencoder();                  //Check encoder and update values

  updateLED();                     //LED on for active state    
//  updateLEDValue(LFO_CH[0], 0); //Update current midi chan for state 0
//  clearLED();                      //LED off (dim light)

  readinputs();
  updatewave();
}

/* =====================================================
==============Get Wave value based on shape=============
======================================================*/ 
char getWaveSample(byte PWMshape, byte tableStep){
    switch (PWMshape) {
      case 1:
        PWMdata = tableStep;
        // Saw wave for shape 1
        break;
      case 2:
        PWMdata = 256-tableStep;
        // Inv Saw wave for shape 2
        break;
      case 3:
        //Triangle wave for shape 3
        PWMdata = tableStep * 2;
        if (tableStep > 127) PWMdata = 256-(2*(tableStep-127)); 
        break;
      case 4: // Step 4
        PWMdata = (tableStep&0b11000000)+64;
        break;
      case 5: // Step 8
        PWMdata = (tableStep&0b11100000)+32;
        break;
      case 6: // Step 16
        PWMdata = (tableStep&0b11110000)+16;
        break;
      case 7: // Step 32
        PWMdata = (tableStep&0b11111000)+8;
        break;
      case 8: // Step 4 + noise
        PWMdata = random(120) * (tableStep>>6);
        break;
      case 9: // Step 8 + noise
        PWMdata = random(60) * (tableStep>>5);
        break;
      case 10: // noise
        PWMdata = random(255);
        break;
      case 11: // noise
        PWMdata = random(128) + tableStep;
        break;
      case 12: // ramp and noise
        if (tableStep < 127 ) {
          PWMdata = 2 * tableStep;
        }
        else {
          PWMdata = random(255);
        }
        break;
      case 13: // half ramp
        if (tableStep < 127 ) {
          PWMdata = 2 * tableStep;
        }
        else {
          PWMdata = 0;
        }
        break;
      case 14: // 25% duty cycle
        if (tableStep < 63 ) {
          PWMdata = 255;
        }
        else {
          PWMdata = 0;
        }
        break;
      case 15: // pulse 6% duty cycle
        PWMdata = 0;
        if (tableStep < 64) {
          PWMdata = 255;
        }
        if (tableStep > 128) {
          if (tableStep < 192) {
            PWMdata = 255;
          }
        }
        break;
      default:
        // Sine wave for shape 0
        PWMdata = waveTable[tableStep];
        break;
    }
    return PWMdata;
}
/* =====================================================
==============Update Wave data pointer==================
======================================================*/ 
void updatewave(){
  if ( millis() >= lastbuttonupdate + 1000 ){
    LFO_CH[state][5] = (analogRead(LeftBottomPot)>>4);          // Update Step Len
    LFO_CH[state][6] = (analogRead(LeftTopPot)>>4);             // Update Delay Time
  }
     for (int i=0; i <= 3; i++){                                // For each channel - i
      if ( millis() >= (lastwaveupdate[i]+LFO_CH[i][6])+1 ){
//      if ( millis() >= (LFO_CH[i][2]+LFO_CH[i][6]) ){
        lastwaveupdate[i] = millis();                          // update "last update" for LFO_CH[state]
        if ( millis() >= lastbuttonupdate + 5000 ){
          if ( LFO_CH[i][1] < 128 ) digitalWrite(LFO_CH[i][4], HIGH);
          if ( LFO_CH[i][1] >= 128 ) digitalWrite(LFO_CH[i][4], LOW);        
        }

//       LFO_CH[i][2] = millis();                               // update "last update" for LFO_CH[state]
        LFO_CH[i][1] = LFO_CH[i][1] + LFO_CH[i][5] + 1;        // update next step in wave table
        PWMdata = getWaveSample(LFO_CH[i][0], LFO_CH[i][1]);   // getWaveSample(shape, tablestep)
        analogWrite(LFO_CH[i][3], PWMdata);
      }
   }
}
/* =====================================================
==============Read Input Values=========================
======================================================*/ 
void readinputs(){
  unsigned int LFOTrig0 = analogRead(RightCenterIn);
  unsigned int LFOTrig1 = analogRead(RightBottomIn);
  unsigned int LFOTrig2 = analogRead(LeftIn);
  
  if ( LFOTrig2 > 255 && trigger[2] == 0 ) {
    LFO_CH[2][1] = 0;
    LFO_CH[3][1] = 0;
    trigger[2] = 1;
    trigger[3] = 1;    
  }
  else{
    if (LFOTrig2 < 255){
      trigger[2] = 0;
      trigger[3] = 0;  
    }
  }

  if ( LFOTrig1 > 255 && trigger[1] == 0 ) {
    LFO_CH[1][1] = 0;
    trigger[1] = 1;
  }
  else{
    if (LFOTrig1 < 255) trigger[1] = 0;
  }
 
  if ( LFOTrig0 > 255 && trigger[0] == 0 ) {
    LFO_CH[0][1] = 0;
    trigger[0] = 1;
  }
  else{
    if (LFOTrig0 < 255) trigger[0] = 0;
  }
}

/* =====================================================
==============Check encoder interrupt===================
======================================================*/ 
void checkencoder(){
  if (left){
    left = false;
    if (encoder[state] != 0) encoder[state]--; // Decrement if not 0
    if (state < 4) {
      if(((LFO_CH[state][0]=encoder[state] >> 2) == 0) && state == 2) LFO_CH[state][0]=16;
      updateLEDValue(LFO_CH[state][0], state);
      EEPROM.write(state, LFO_CH[state][0]);
    }
  }
  if (right){
    right = false;
    if (encoder[state] < 0x3f) encoder[state]++;
    if (state < 4) {
      LFO_CH[state][0]=encoder[state] >> 2;
      updateLEDValue(LFO_CH[state][0], state);
      EEPROM.write(state, LFO_CH[state][0]);
    }
  }
  if (button){
    button = false;    
    buttoncnt++;
    buttoncnt = buttoncnt & B00000111;
    EEPROM.write(state+StepA4EEPROM, LFO_CH[state][5]);
    EEPROM.write(state+StepA5EEPROM, LFO_CH[state][6]);
    state = buttoncnt >> 1;
    lastbuttonupdate = millis(); 
    }
}
/* =====================================================
==============Update LED Values based on input==========
======================================================*/ 
void updateLEDValue(unsigned int nibble,unsigned int updstate)
{
  if (nibble >= 0x10) nibble = 0x0f;
  else (nibble = nibble & 0x0f);
  if (nibble & 0x01){
//    LED1Data = true;
    LEDData[updstate][0] = true;
  }
  else {
//    LED1Data = false;
    LEDData[updstate][0] = false;
  }
  if (nibble & 0x02){
//    LED2Data = true;
    LEDData[updstate][1] = true;
  }
  else {
//    LED2Data = false;
    LEDData[updstate][1] = false;
  }
  if (nibble & 0x04){
//    LED3Data = true;
    LEDData[updstate][2] = true;
  }
  else {
//    LED3Data = false;
    LEDData[updstate][2] = false;
  }
  if (nibble & 0x08){
//    LED4Data = true;
    LEDData[updstate][3] = true;
  }
  else {
//    LED4Data = false;
    LEDData[updstate][3] = false;
  }

}
/* =====================================================
==============Update LED's based on LED Values==========
======================================================*/ 
void updateLED(){
  digitalWrite(LED1, LEDData[state][0]);
  digitalWrite(LED2, LEDData[state][1]);
  digitalWrite(LED3, LEDData[state][2]);
  digitalWrite(LED4, LEDData[state][3]);
  delay(1);
  if ( millis() < lastbuttonupdate + 10000 ){
    digitalWrite(LED_Out6, state == 0);
    digitalWrite(LED_Out9, state == 1);
    digitalWrite(LED_Out10, state == 2);
    digitalWrite(LED_Out11, state == 3);
  }
}

void clearLED(){
  digitalWrite(LED1, LOW);
  digitalWrite(LED2, LOW);
  digitalWrite(LED3, LOW);
  digitalWrite(LED4, LOW);
  digitalWrite(LED_Out6, LOW);
  digitalWrite(LED_Out9, LOW);
  digitalWrite(LED_Out10, LOW);
  digitalWrite(LED_Out11, LOW);
}

/* =====================================================
==============Encoder change interrupt==================
======================================================*/  
ISR (PCINT1_vect) {
// If interrupt is triggered by the button
  boolean SW_val = digitalRead(SWpin);
  if (SW_val != SW_old) {
    SW_old = SW_val;
    button = true;}

// Else if interrupt is triggered by encoder signals
  else {
    
    // Read A and B signals
    boolean A_val = digitalRead(Apin);
    if (A_val != A_old) {
      A_old = A_val;
      if (A_val^B_old) {
        left = true; //swap dir
//        right = true;
      }
      else {
        right = true; //swap dir
//        left = true;
      }
    }
    else {
      boolean B_val = digitalRead(Bpin);
      B_old = B_val;
      if (A_val^B_val) {
        right = true; //swap dir
//        left = true;
      }
      else {
        left = true; //swap dir
//        right = true;
      }
    }
  }
}

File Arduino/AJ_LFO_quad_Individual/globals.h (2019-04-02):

#include <EEPROM.h>
/* -----------------------------------------------
 *  GLOBAL DEFINES
 * -----------------------------------------------
 */
//OVERRIDE PINS FOR LFO
#define LFO0 6 // Sets Pin PWM1 = Out 6 (top right)
#define LFO1 11 // Sets Pin PWM2 = Out 11 (mid right)
#define LFO2 10 // Sets Pin PWM6 = Out 10 (top left)
#define LFO3 9 // Sets Pin PWM4 = Out 9 (mid left)

#define SWpin A0 //add 100nF to GND for debounce 
#define Apin A1 //add 100nF to GND for debounce
#define Bpin A2 //add 100nF to GND for debounce

#define LeftIn A3 // Lowest Left feeds to left two top outputs
#define LeftBottomPot A4 // Addon board
#define LeftTopPot A5 // Addon board
#define RightCenterIn A6 // Feeds to Right Top out
#define RightBottomIn A7 // Feeds to Right Center out

#define LED1 2
#define LED2 3
#define LED3 4
#define LED4 5
#define LED_Out6 7
#define LED_Out9 13
#define LED_Out10 12
#define LED_Out11 8

/* -----------------------------------------------
 *  GLOBAL VAR
 * -----------------------------------------------
 */
boolean A_old=0, B_old=1, SW_old=0;
boolean left = false, right = false, button = false;

boolean LEDSelData = false, LEDSel2Data = false; 
unsigned int encoder[4], buttoncnt = 0;
unsigned int state = 0; 
//For LFO - State 00 = Out6 - 01 = Out9 - 10 = Out10 - 11 = Out11
byte LFO_CH[4]; //(see state above)
boolean LEDData[4][4]; //(see state)

unsigned long lastwaveupdate = 0; // LFO millis timer between samples
unsigned int delayTime = 4; 
uint8_t tableStep = 0;
uint8_t PWMdata = 0;

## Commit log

2019-02-05 Initial sch
    [Kicad-EffectsUnit1.kicad_pcb, Kicad-EffectsUnit1.sch]
2019-02-05 Sch added switches and clipping diodes - init pcb
    [Kicad-EffectsUnit1.kicad_pcb, Kicad-EffectsUnit1.sch]
2019-02-05 Initial PCB and png
    [_saved_Kicad-EffectsUnit1.sch]
2019-02-06 PT2399 started
    [Kicad-EffectsUnit1.sch, KicadJE-EU1-PT2399_sub.sch, _saved_Kicad-EffectsUnit1.sch]
2019-02-06 anti latchup initiated
    inspiration:
    https://www.electrosmash.com/images/tech/pt2399/PT2399_Transistor_Current_Sink_Pin6.png
    [Kicad-EffectsUnit1.kicad_pcb, KicadJE-EU1-PT2399_sub.sch]
2019-02-06 Basic circuit done
    [Kicad-EffectsUnit1.sch, KicadJE-EU1-PT2399_sub.sch]
2019-02-06 more footprints
    [Kicad-EffectsUnit1.sch, KicadJE-EU1-PT2399_sub.sch]
2019-02-09 footprint juggling
    [Kicad-EffectsUnit1.sch, KicadJE-EU1-PT2399_sub.sch]
2019-02-11 Pin juggling on bit crusher
    [Kicad-EffectsUnit1.sch, KicadJE-EU1-PT2399_sub.sch, _saved_Kicad-EffectsUnit1.sch]
2019-02-24 PCB work
    [Kicad-EffectsUnit1.kicad_pcb]
2019-02-24 sch pinout
    [Kicad-EffectsUnit1.sch]
2019-02-24 3D + PCB
    [Kicad-EffectsUnit1.kicad_pcb, _saved_Kicad-EffectsUnit1.sch]
2019-02-24 Removed components from PSU
    [Kicad-EffectsUnit1.kicad_pcb, Kicad-EffectsUnit1.sch, _saved_Kicad-EffectsUnit1.sch]
2019-02-24 PREPARE for major restruct
    [Kicad-EffectsUnit1.kicad_pcb, Kicad-EffectsUnit1.sch, _saved_Kicad-EffectsUnit1.sch]
2019-02-24 Reorganize #1
    [Kicad-EffectsUnit1.kicad_pcb]
2019-02-24 Distortion - Bitcrunch components placed
    [Kicad-EffectsUnit1.kicad_pcb]
2019-02-24 Before gnd flooding
    [Kicad-EffectsUnit1.kicad_pcb]
2019-02-25 DRC done for Cruncher/Distortion
    [Kicad-EffectsUnit1.kicad_pcb]
2019-02-25 Remove extra components from PT2399 and add EU3 diagram
    [EU3.sch, Kicad-EffectsUnit1.sch, KicadJE-EU1-PT2399_sub.sch]
2019-02-25 GNDS and GNDA
    [KicadJE-EU1-PT2399_sub.sch]
2019-02-25 argh Kicad not stable
    [KicadJE-EU1-PT2399_sub.sch, _saved_EU3.sch, _saved_KicadJE-EU1-PT2399_sub.sch]
2019-02-25 Components placed on PT2399
    [Kicad-EffectsUnit1.kicad_pcb, KicadJE-EU1-PT2399_sub.sch]
2019-02-25 Added 78L05 reg
    [Kicad-EffectsUnit1.kicad_pcb, KicadJE-EU1-PT2399_sub.sch]
2019-02-25 Counter and Clock added to EU-3
    [EU3.sch]
2019-02-26 change jacks
    [EU3.sch]
2019-02-26 SO8 SO16
    [EU3.sch]
2019-02-26 -12Vc and Opamp removed on Clock sch
    [EU3.sch]
2019-02-26 Large components placed EU3
    [EU3.sch, Kicad-EffectsUnit1.kicad_pcb]
2019-02-26 Replace 16pin doepfer with 10pin on EU3
    [EU3.sch, KicadJE-EU1-PT2399_sub.sch]
2019-02-26 EU3 placed and routed
    [EU3.sch, Kicad-EffectsUnit1.kicad_pcb]
2019-02-26 Labels and logos done
    [Kicad-EffectsUnit1.kicad_pcb]
2019-02-28 3D and replaced som top silk text
    [Kicad-EffectsUnit1-B.Cu.gbr, Kicad-EffectsUnit1-B.Mask.gbr, Kicad-EffectsUnit1-B.Paste.gbr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]
2019-03-31 filters 2
    [Kicad-EffectsUnit1.sch]
2019-04-01 Arduino LFO initiated
    [_saved_Kicad-EffectsUnit1.sch]
2019-04-01 LFO with distortion tested nicely!
    [Kicad-EffectsUnit1.kicad_pcb, Kicad-EffectsUnit1.sch, _saved_Kicad-EffectsUnit1.sch]
2019-04-02 Arduino - trigger ino
2019-04-02 Arduino - trigger - LFO 2D config array
2019-04-02 Arduino - LFO's broken
    [AJ_LFO_quad_trigger.ino, globals.h]
2019-04-02 Arduino - LFO w individual waveform and individual timebase working.
2019-04-03 LED output delayed 10000ms - A4 A5 controls delayed 1000ms - LFO sync LED delayed 5000ms
2019-04-25 Rev B initiated
    [EU3.sch, Kicad-EffectsUnit1.sch, KicadJE-EU1-PT2399_sub.sch]
2019-04-25 Counter with input protection and new stop/carry feature
    [EU3.sch]
2019-04-25 Switch 1/2 rev
    [Kicad-EffectsUnit1.sch]
2019-09-29 Rev 1,2 Counter Resistor on LED
    [EU3.sch]
